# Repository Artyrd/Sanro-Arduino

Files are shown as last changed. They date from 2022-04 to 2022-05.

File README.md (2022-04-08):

# Sanro - Arduino
（このREADME.mdは日本語訳版があります、README_JP.mdをご覧ください、訳は完璧には程遠いですが）  
Hardware program of the game Taiko Sanro.

## What is This Program

Music game fans from East Asia countries are most probable to know a famous game called Taiko No Tatsujin ([太鼓の達人](http://taiko-ch.net/)), developed by [Bandai Namco Entertainment](http://bandainamcoent.co.jp/).

This open-source program aims to help you develop your own **hardware taiko** at home, just like how you play taiko in arcade halls.

*This program is for personal and non-commercial use only. You may design your own taiko and have fun, but you may NOT distribute your product to the public.*

## Features

* **Full support for the PC game Taiko-san Jiro (太鼓さん次郎).** Actually, any app/game/emulator using keyboards as input is supported.
* **Force-sensitive.** I am also developing a new open-source game called Taiko Sanro that can support this feature.
* **Supports dense inputs such as rolling.**

*In one word, your taiko will perform exactly the same as the arcade version if you configure the program well enough! :D*

## Prerequisites

Because this is a DIY project, you should have some basic  electronic engineering knowledge about connecting microprocessors with jumper wires on a breadboard. **Soldering techniques, however, are NOT required.**

## Getting Started

It might take you a few days to assembly and configure your own taiko device. The microprocessor chips are cheap, though, you can buy them from wherever you want.

### Preparation

Almost all of these things have alternatives, now I will show you what I used:

* [Arduino Micro](http://i.imgur.com/lXqnpJ9.jpg) module x 1
* [KEYES K-036](http://i.imgur.com/gUWnUCc.png) microphone module x 4
* Breadboard x 1
* A few jumper wires
* Micro USB cable x 1
* [Arduino IDE](https://www.arduino.cc/en/Main/Software)

And miscellaneous stuffs like:

* Thick wood plank x 4, best to be [shaped like this](http://i.imgur.com/va20eVn.jpg)
* Foamed plastics to connect and fixate the wood
* Superglue
* Other electronical tools like screw drivers and multimeters, etc.

A few things to note:

1. Any Arduino modules with ATmega32u4 chips or Due and Zero boards are supported. Arduino Micro is the cheapest one, though.
2. Using a breadboard is a low-cost option, but it is not the best/stablest choice. There is a PCB blueprint that allows you to print the integrated board and solder up. For details, please see "Making the PCB" part below.
3. You can also design and build your own microphones modules, just make sure you know how to connect them to your Arduino module.
4. Thick, solid, dense and heavy wood is the best choice, while plywood, particleboard and medium-density fiberboard (MDF) are fragile at their edges and can be easily damaged. For better experience, you should cut the planks with the shapes shown in [the picture](http://i.imgur.com/va20eVn.jpg). If you don't have the cutting tools and want it easier, just prepare 4 planks.

### Connecting the Parts

The scheme is quite simple. You don't even need any extra resistors or capacitors. **All you need are jumper wires.**

Each microphone module has 4 pins, and we only need 3 of them (`A0`, `+`, and `G`). Connect their `A0` outputs to Arduino Micro's `A0`~`A3` inputs, then connect their `+` pins together with module's `5V` pin, then the `G` pins together to the ground. Use the following picture if you have any problems.

(Picture to be uploaded)

### (Optional) Making the PCB

To make the PCB, you can either DIY or ask local PCB manufacturer for help. If you choose DIY, you should prepare a few more things, including:

* 2.2 x 1.6 inches Empty PCB x 1
* Thermal transfer paper x 1
* Laser printer x 1
* Standard 4-pin header x 4
* Thermal transfer machine (or clothes iron)
* Etchant
* Soldering tools

Detailed process to make the PCB is totally off-topic, and you may need [this video](https://www.youtube.com/watch?v=mv7Y0A9YeUc) to help you. I have included the required printable board file `sanro.eps` in the `Eagle/sanro-arduino` folder. You can also download the scheme and board files and edit them by yourself with the [Eagle Software](http://www.cadsoftusa.com/download-eagle/).

### Uploading the Program to the Board

1. Download and install [Arduino IDE](https://www.arduino.cc/en/Main/Software).
2. Create a folder and put the source files (`sanro.ino` and `cache.h`) into it.
3. Connect your Arduino Micro to your computer with a USB cable. The driver installation should be automatic, but if you have any questions about it, [check this official guide](https://www.arduino.cc/en/Guide/ArduinoLeonardoMicro#toc8).
4. Open the `sanro` project in Arduino IDE.
5. Select "Board" - "Arduino/Genuino Micro" from the menu.
6. Compile and upload the program.

## Configuration

***WARNING: Because of the deviations between the microphones and the installation of the planks, you will spend much time adjusting the hardware and the parameters in the program. Be patient, there are lots of tries-and-errors up ahead.***

### Hardware

Literally there is only 2 things you need to do:

1. Glue each microphone to the wood plank
2. Fixate the wood planks onto the foamed plastics 

However, the problem is how you do them. There are some major criteria when doing this job:

* Attach the microphone to the plank as close/tight as possible
* Seal the microphone to isolate it from outside noises
* Don't let the planks contact each other

To accomplish them, you can remove the filter cover of the microphone receiver, then attach the receiver face (the microphones are usually cylindrical, like [the ones that I used in this project](http://i.imgur.com/gUWnUCc.png)) tightly to the surface of the plank, and seal it with superglue. In this way, the soundwave from the plank can be directly transmitted to the microphone, loud and clear. Also, noises and soundwave from nearby planks can be reduced to the minimum.

Also, please note that there is a potentiometer on the KEYES module, which is used to set the quiescent operating point (Q-point) of the microphone. Although I have implemented algorithms to eliminate the bias caused by unequal Q-point of each microphone, **it is better to adjust the potentiometer manually and keep the Q-points at approximately the same level.** To do this, you may need to contact your microphone provider.

### Parameters in the Program

All you need to change is the `LIGHT_THRES` and the `HEAVY_THRES`, according to your microphone configuration.

The codes are short and self-explanatory, and if you need help understanding them, please refer to the "About the Algorithm" part.

(To be completed)

## About the Algorithm

The algorithm in the program is simple, and there are still much more to be optimized. All pull requests are welcomed!

In short, the signal processing job can be divided into 4 calculating steps after acquiring the samples from the analog inputs:

1. Calculate the derivative
2. Calculate the power of the waveform
3. Calculate the convolution of the power
4. Find the peak of the power convolution and compare it with the thresholds to see if there is a light or heavy hit

This picture shows the algorithm in a clearer way:

(Picture to be uploaded)

Step 1 is to elinimate the difference of Q-point, which makes it easier and more accurate to calculate the power of the waveform.

Step 2, calculating the power of the waveform, can also enhance the signal to noise ratio (SNR), which can further eliminate the noises. `LIGHT_THRES` is also used here to cut the low-power noises out.

Step 3 is to "polish" the power curve to make it more like a sequence of hit pulses, which makes it easier to find the power peak.

For Arduino microprocessors, the executing time for each loop is not stable - the processor always executes the instructions as fast as it can. Onece the loop ends, it immediately starts the next loop. This is extremely bad for sampling sounds. Therefore, the program implements a simple sampling frequency control mechanism to restrict the sampling frequency to no more than 1,000Hz.

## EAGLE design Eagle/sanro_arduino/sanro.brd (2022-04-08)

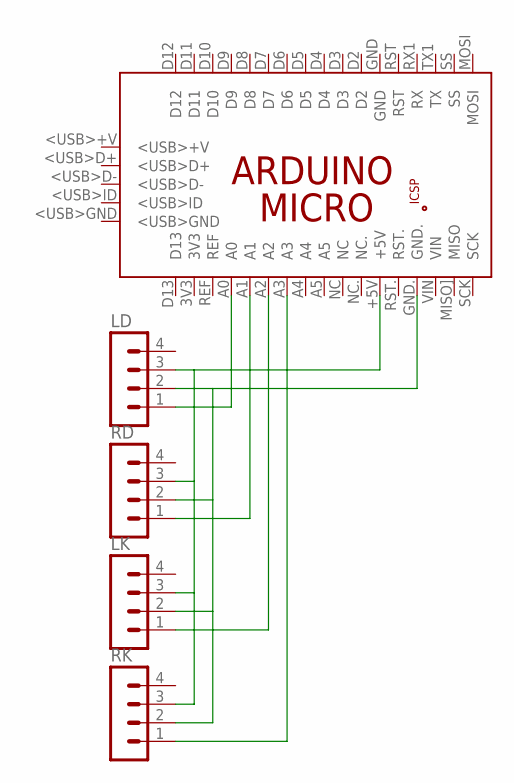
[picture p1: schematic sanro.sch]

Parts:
LD: MA04-1
LK: MA04-1
PCB1: ARDUINO_MICRO
RD: MA04-1
RK: MA04-1

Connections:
unnamed: LD.1, PCB1.A0
unnamed: PCB1.A1, RD.1
unnamed: LK.1, PCB1.A2
unnamed: PCB1.A3, RK.1
unnamed: LD.2, LK.2, PCB1.GND., RD.2, RK.2
unnamed: LD.3, LK.3, PCB1.+5V, RD.3, RK.3

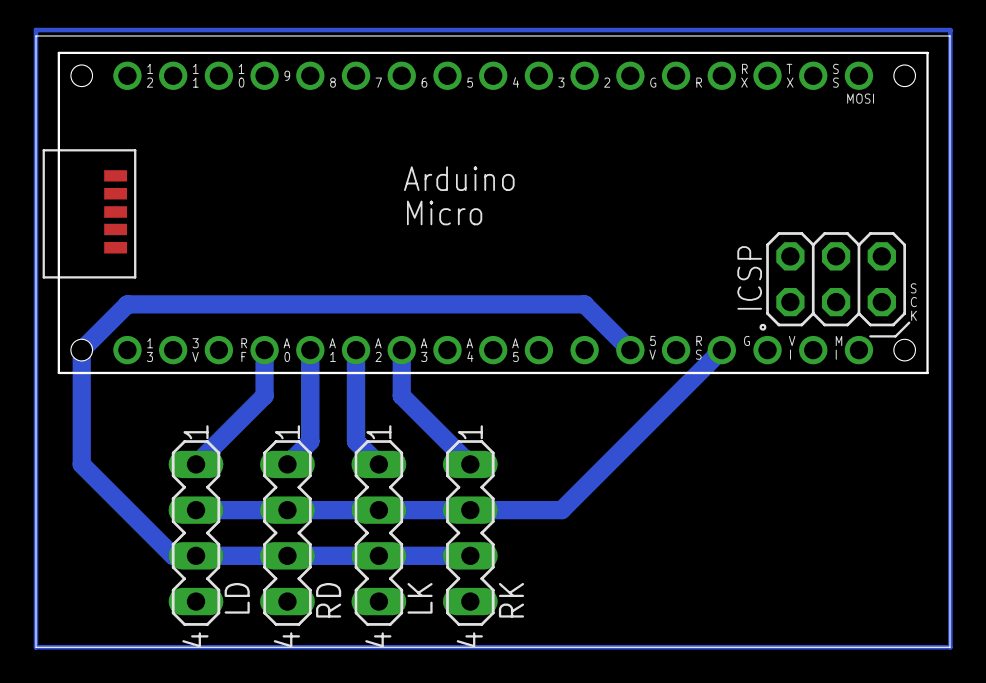
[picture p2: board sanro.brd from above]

Board: 2 copper layers, 50.8 x 34.0 mm, 5 parts (0 on the bottom side), 6 nets.

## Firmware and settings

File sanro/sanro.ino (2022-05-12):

/***************************************************************
 *                                                             *
 *                Taiko Sanro - Arduino                        *
 *   Support Arduino models with ATmega32u4 microprocessors    *
 *                                                             *
 *          Shiky Chang                    Chris               *
 *     zhangxunpx@gmail.com          wisaly@gmail.com          *
 *                                                             *
 ***************************************************************/

#include <limits.h>
#include <Keyboard.h>
#include "cache.h"

//Taiko Jiro by default, Sanrio if defined
//#define MODE_SANRO

// #define ENABLE_NS_JOYSTICK // Nintendo Switch compatability, 0 otherwise
// #define ENABLE_KEYBOARD // Enables Keyboard, not needed if you toggle

// enable toggling between keyboard and nintendo switch
#define ENABLE_TOGGLE 1 // 0 if no toggle, 1 if toggle
#define TOGGLEPIN 7

#define MODE_DEBUG 0

#define CHANNELS 4

// Caches for the soundwave and power
//#define SAMPLE_CACHE_LENGTH 12
#define SAMPLE_CACHE_LENGTH 20
#define POWER_CACHE_LENGTH 5

// Light and heacy hit thresholds
#define LIGHT_THRES 5000

#if MODE_JIRO // disable heavy hits
  #define HEAVY_THRES LONG_MAX
#else
  #define HEAVY_THRES 20000
#endif

long int thresh[4] = {5000, 5000, 5000, 5000};

// Forced sampling frequency
#define FORCED_FREQ 1000
long int cycleTime = 1000000 / FORCED_FREQ;

// bool enable_keyboard = false;
bool mode_switch = true;

unsigned long int lastTime;

int channelSample [CHANNELS];
int lastChannelSample [CHANNELS];
Cache <int, SAMPLE_CACHE_LENGTH> sampleCache [CHANNELS];

long int frame = 0;
int frame_cycle = 10;

long int power [CHANNELS];
Cache <long int, POWER_CACHE_LENGTH> powerCache [CHANNELS];

bool triggered [CHANNELS];
bool ns_inputted = false;

bool printed[CHANNELS];

int pins[] = {A0, A3, A1, A2};  // L ka, R ka, L don, R don
char lightKeys[] = {'e', 'i', 'f', 'j'}; // L ka, R ka, L don, R don

#ifdef MODE_SANRO
char heavyKeys[] = {'r', 'g', 'h', 'u'};
#endif

bool down[4] = {false, false, false, false};

// #ifdef ENABLE_NS_JOYSTICK
#include "Joystick.h"
//const int sensor_button[4] = {SWITCH_BTN_ZL, SWITCH_BTN_ZR, SWITCH_BTN_B, SWITCH_BTN_A};
//   taiko force layout:  <  >  B  A
const int sensor_button[4] = {SWITCH_BTN_NONE, SWITCH_BTN_A, SWITCH_BTN_NONE, SWITCH_BTN_B}; // L ka, R ka, L don, R don 
const int sensor_hat[4] = {SWITCH_HAT_L, 0, SWITCH_HAT_R, 0};
uint8_t down_count[4] = {0, 0, 0, 0};
// #endif

bool newlinePrinted = false;

void setup() {
  Serial.begin (9600);
  #ifdef ENABLE_TOGGLE
    pinMode(TOGGLEPIN, INPUT_PULLUP);
    if (digitalRead(TOGGLEPIN) == true) {
      mode_switch = true;
    } else {
      mode_switch = false;
    }
    attachInterrupt(digitalPinToInterrupt(TOGGLEPIN), button_ISR, CHANGE);
  #endif

  Keyboard.begin ();
  analogReference (DEFAULT);
  //analogSwitchPin(pins[0]);
  pinMode(LED_BUILTIN, OUTPUT);
  digitalWrite(LED_BUILTIN, LOW);
  for (short int i = 0; i < CHANNELS; i++) {
    power [i] = 0;
    lastChannelSample [i] = 0;
    triggered [i] = false;
  }
  lastTime = 0;
  /*
  if (mode_switch) {
    for (int i = 0; i < 8; ++i) pinMode(i, INPUT_PULLUP);
  }
  */
}

void loop() {
  
  for (short int i = 0; i < CHANNELS; i++) {
    
    channelSample[i] = analogRead(pins [i]);
    sampleCache[i].put(channelSample[i] - lastChannelSample[i]);
    
    long int tempInt;
    tempInt = sampleCache[i].get (-10); // get the oldest reading (12th)
    power [i] -= tempInt * tempInt;
    tempInt = sampleCache[i].get (); // get the newest reading
    power [i] += tempInt * tempInt;
    if (power [i] < LIGHT_THRES) {
      power [i] = 0;
    }
    powerCache [i].put (power [i]);
    //lastChannelSample [i] = channelSample [i];
    //if (powerCache [i].get (1) == 0) {
    if (powerCache [i].get (-1) == 0) {
      triggered [i] = false;
      printed[i] = false;
    }

    if (!triggered [i]) {
      for (short int j = 0; j < POWER_CACHE_LENGTH - 1; j++) {
        if (powerCache[i].get (j - 1) >= powerCache[i].get (j)) {
          break;
        // heavy hits don't register in taiko jiro mode
#ifdef MODE_SANRO
        } else if (powerCache [i].get (1) >= HEAVY_THRES) {
          triggered [i] = true;
          Keyboard.print (heavyKeys[i]);
          break;
#endif
        } else if (powerCache [i].get(-1) >= thresh[i]) {
          // disable don hit if same-side ka is stronger
          if (i == 2 && powerCache[2].get(-1) < powerCache[0].get(-1)) {
            break;
          } else if (i == 3 && powerCache[3].get(-1) < powerCache[1].get(-1)) {
            break;
          }
          // if (!mode_switch) {
          //   Keyboard.print (lightKeys[i]);
          // }
          triggered [i] = true;
          printed[i] = true;
          
          // #ifdef ENABLE_NS_JOYSTICK
          if (down_count[i] <= 2) {
            down_count[i] += 1;
          }
          // #endif

          break;
        }
      }
    }
    // End of each channel
  }

  // #ifdef ENABLE_NS_JOYSTICK
  frame++;
  if (frame > frame_cycle) {
    if (down_count[0] || down_count[1] || down_count[2] || down_count[3]) {
      frame = 0;
      // Serial.print(String(down_count[0]) + " " + String(down_count[1]) + " " + String(down_count[2]) + " " + String(down_count[3]) + "\n");
      Joystick.HAT = 0;
      for (int i = 0; i < 4; i++) {
        // bool state = (down_count[i] & 1);
        bool state = (bool) down_count[i];
        Joystick.Button |= (state ? sensor_button[i] : SWITCH_BTN_NONE);
        Joystick.HAT |= (state ? sensor_hat[i] : 0);
        down_count[i] -= (bool)down_count[i];
        if (state && !mode_switch) {
          Keyboard.print (lightKeys[i]);

        }
      }
      if (Joystick.HAT == 0) { 
        Joystick.HAT = SWITCH_HAT_CENTER;
      }
      if (mode_switch) {
        Joystick.sendState();
        Serial.print("Button:" + (String)Joystick.Button + " HAT:" + (String)Joystick.HAT +"\n");
      }
      
      Joystick.Button = SWITCH_BTN_NONE;
      Joystick.HAT = SWITCH_HAT_CENTER;;
    } else if (frame > frame_cycle * 4 && mode_switch) {
      frame = 0;
      Joystick.sendState();
    }
  }
  //#endif

  #if MODE_DEBUG
    if (power[0] || power[1] || power[2] || power[3] || true) {
      Serial.print(String(power[0]) + "\t" + String(power[1]) + "\t" + String(power[2]) + "\t" + String(power[3]));
      Serial.print("\t | ");
      Serial.print(String(channelSample[0]) + "\t" + String(channelSample[1]) + "\t" + String(channelSample[2]) + "\t" + String(channelSample[3]));
      //Serial.println(String(channelSample[0]-lastChannelSample[0]) + "\t" + String(channelSample[1]-lastChannelSample[1]) + "\t" + String(channelSample[2]-lastChannelSample[2]) + "\t" + String(channelSample[3]-lastChannelSample[3]));
      Serial.print("\t | ");
      Serial.print(String(printed[0]) + "\t" + String(printed[1]) + "\t" + String(printed[2]) + "\t" + String(printed[3]));
      Serial.print("\n");
      newlinePrinted = false;
    } else if (!newlinePrinted) {
      Serial.println("\n");
      newlinePrinted = true;
    }
  #endif
 
  for (int i = 0; i < CHANNELS; i++) {
    lastChannelSample [i] = channelSample [i];
  }

  // Force the sample frequency to be less than 1000Hz
  unsigned int frameTime = micros () - lastTime;
  if (frameTime < cycleTime) {
    delayMicroseconds (cycleTime - frameTime);
  } else {
    // Performance bottleneck;
    //Serial.println ("Exception: forced frequency is too high for the microprocessor to catch up.");
  }
  lastTime = micros ();
}

#ifdef ENABLE_TOGGLE
void button_ISR(){
  if (digitalRead(TOGGLEPIN) == true) {
    mode_switch = true;
  } else {
    mode_switch = false;
  }
}
#endif

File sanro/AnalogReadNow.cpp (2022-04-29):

  #include "AnalogReadNow.h"

#include "wiring_private.h"
#include "pins_arduino.h"

void analogSwitchPin(uint8_t pin)
{
#if defined(analogPinToChannel)
#if defined(__AVR_ATmega32U4__)
	if (pin >= 18) pin -= 18; // allow for channel or pin numbers
#endif
	pin = analogPinToChannel(pin);
#elif defined(__AVR_ATmega1280__) || defined(__AVR_ATmega2560__)
	if (pin >= 54) pin -= 54; // allow for channel or pin numbers
#elif defined(__AVR_ATmega32U4__)
	if (pin >= 18) pin -= 18; // allow for channel or pin numbers
#elif defined(__AVR_ATmega1284__) || defined(__AVR_ATmega1284P__) || defined(__AVR_ATmega644__) || defined(__AVR_ATmega644A__) || defined(__AVR_ATmega644P__) || defined(__AVR_ATmega644PA__)
	if (pin >= 24) pin -= 24; // allow for channel or pin numbers
#else
	if (pin >= 14) pin -= 14; // allow for channel or pin numbers
#endif

#if defined(ADCSRB) && defined(MUX5)
	// the MUX5 bit of ADCSRB selects whether we're reading from channels
	// 0 to 7 (MUX5 low) or 8 to 15 (MUX5 high).
	ADCSRB = (ADCSRB & ~(1 << MUX5)) | (((pin >> 3) & 0x01) << MUX5);
#endif
  
	// set the analog reference (high two bits of ADMUX) and select the
	// channel (low 4 bits).  this also sets ADLAR (left-adjust result)
	// to 0 (the default).
#if defined(ADMUX)
#if defined(__AVR_ATtiny25__) || defined(__AVR_ATtiny45__) || defined(__AVR_ATtiny85__)
	ADMUX = (DEFAULT << 4) | (pin & 0x07);
#else
	ADMUX = (DEFAULT << 6) | (pin & 0x07);
#endif
#endif

	// without a delay, we seem to read from the wrong channel
	//delay(1);

#if defined(ADCSRA) && defined(ADCL)
	// start the conversion
	sbi(ADCSRA, ADSC);
#endif
}

int analogReadNow()
{
#if defined(ADCSRA) && defined(ADCL)
	// ADSC is cleared when the conversion finishes
	while (bit_is_set(ADCSRA, ADSC));
	
	// we have to read ADCL first; doing so locks both ADCL
	// and ADCH until ADCH is read.  reading ADCL second would
	// cause the results of each conversion to be discarded,
	// as ADCL and ADCH would be locked when it completed.
	uint8_t low, high;
	low  = ADCL;
	high = ADCH;
	
	// combine the two bytes
	return (high << 8) | low;
#else
	// we dont have an ADC, return 0
	return 0;
#endif
}

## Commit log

2022-04-08 moved lastTime re-assignment to after delay
    [sanro.brd, sanro.sch]
2022-04-19 started adding LuiCat's switch support
2022-04-29 works with nintendo switch ft saer debel
2022-04-29 removed need to break during ns button pressing
